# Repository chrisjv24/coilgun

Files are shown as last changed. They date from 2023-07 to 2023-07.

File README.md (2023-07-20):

# coilgun
This repository will contain all design files and documentation concerning the Carter X Chris coilgun design.

## Repo Architecture
The repo will be split into the four subsystems of chassis, propulsion, controls, and safety, along with an additional directory for non-technical documents.

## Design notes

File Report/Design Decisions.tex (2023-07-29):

\chapter{Design Decisions}
The system was divided into the following four subsystems: Mechanical Housing, Electrical Circuitry, Coding, and Safety. Each of these systems has their own unique design considerations that are to be explored and addressed.

\section{Electrical System}

The electrical system is the backbone of the project, being the main method of propulsion. This portion can be further broken down into the following: Power, capacitor charging, firing, and coil shutoff.

\subsection{Power}

The power system will need to provide adequate voltage for both the capacitors and micro-controller. The initial micro-controller choice is the Arduino Nano, which requires a 7-12V input. Therefore, either a 3S Lithium-Polymer (Li-Po) or 3 lithium ion 18650 batteries will be sufficient. This battery chemistry was chosen for its large capacity and the ability to recharge the batteries. However, to properly power the capacitor banks, a boost converter must be used to step up the battery voltage to 200-450V. A two stage DC-DC converter will be purchased off of Ali-Express to step up the voltage.

\begin{figure}
	
\end{figure}

The basic boost converter topology shown above can be characterized by first starting with the standard current and voltage equations for inductors and capacitors. 

For inductors, we have 
\begin{equation}
	V_{In}=L\frac{di}{dt}
\end{equation}

where \(V_{In}\) is the input voltage, L is the inductance of the inductor in Henries, and \(\frac{di}{dt}\) is the change in current across the inductor. For a single switching cycle, we have that \(\frac{di}{dt}\) is equal to the change in current across the period of the cycle, T. 

\begin{equation}
	V_{In}=L\frac{\Delta i}{T}
\end{equation}

Switching period is also defined as the inverse of the switching frequency \(f_S\). For the voltage across the inductor during only the ON portion of the cycle, the period is also multiplied by the duty cycle \(D\). Rearranging gives

\begin{equation}
	\Delta i=\frac{V_{In} D}{f_S L}
\end{equation}

Similarly, the capacitor can be modelled according to

\begin{equation}
	i=C_v\frac{dV}{dt}
\end{equation}

where \(C\) is the capacitance.
\subsubsection{Capacitor Charging}

The system will use 450V 1000uF capacitors to store energy. In order to charge the capacitors, direct connection to the boost converters will be required. An indicator with a digital display of the boost converter output voltage will be fixed onto the housing, with the assumption that, due to the low capacitance values, the capacitor charge simultaneously match the output. The digital voltage meter will consist of a voltage divider to step down 500V to within a 0-5V range. A voltage divider circuit can be simply modelled through Ohm's Law -- \(V=IR\). From the circuit diagram below, the voltage drop across \(R_2\) can be derived as follows

\begin{equation}
	V_in=IR_Total
	V_in
\end{equation}

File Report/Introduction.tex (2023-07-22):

\addcontentsline{toc}{chapter}{Introduction}
\chapter{Introduction}

Launching small projectiles is not a simple task. Traditional methods of propelling objects involve converting stored potential, such as chemical energy within gunpowder or mechanical energy stored in springs, into kinetic energy. However, electrical energy has been underutilized and often seen as a power source for motors or pumps rather than direct energy conversion. 

\section{Background Theory}
When an electric current flows through a wire, a magnetic field is induced. The strength and direction of this magnetic field are governed by the equation 

\begin{equation}
	\vec{B}(r)=\frac{\mu_0}{4\pi}\oint_C \frac{I \,dl \times (\vec{r}-\vec{r'})}{|\vec{r}-\vec{r'}|^3},
\end{equation} 

\noindent also known as the Biot-Savart Law, where \(\vec{B}(r)\) is the magnetic field at point \(r\) in teslas, \(I\) is current in Amperes, \(\,dl\) is a vector along path \(C\), \(r'\) is the position of source current at point \(l\), and \(\mu_0\) is the permeability of free space with a value of \(4\pi \times 10^-7 \frac{Tm}{A}\). If the wire were wound into loops, as in the case of a solenoid, then by placing the origin at the centre of the loops and calculating the magnetic field at \(r=0\), the magnetic field would be given by

\begin{equation}
	\vec{B}(r)=\frac{\mu_0}{4\pi}\oint_C \frac{I \,dl \times -\vec{r'}}{|\vec{r'}|^3}.
\end{equation}

\noindent For circular loops in a cylindrical coordinate system, the \(\,dl\) element is in the \(\hat{\phi}\) direction, \(\vec{r'}\) is only in the \(\hat{s}\) direction, and the cross product \(\,dl \times -\vec{r'}\) evaluates to be in the \(\hat{z}\) direction. Since a vector in the direction of the circular wire is always orthogonal to the radial vector \(\hat{s}\), the cross product integral (assuming a constant \(I\)) simplifies to 

\begin{equation}
	\vec{B}(r)=\frac{\mu_0 I}{4\pi}\hat{z}\oint_C \frac{ \,dl \vec{r'}}{|\vec{r'}|^3}=\frac{\mu_0 I}{4\pi r^2}\hat{z}\oint_C {\,dl}
\end{equation}

\noindent Here, the line integral evaluates to the length of the wire in the solenoid, which can be calculated by taking the circumference of the loops, $2\pi r$, multiplied by the number of loops $N$. Thus, the magnetic field is given by 

\begin{equation}
	\vec{B}=\frac{\mu_0 IN}{2r'}\hat{z}
\end{equation}

\noindent For a given projectile, its motion is described through Newton's Second Law. Assuming friction forces are negligible, then the acceleration of a ferromagnetic object of mass $m$ is 

\begin{equation}
	\vec{a} = \frac{\vec{F_{net}}}{m}=\frac{\vec{B}}{m}=\frac{\mu_0 IN}{2r'm}\hat{z}
\end{equation}

\noindent From the constant current assumption, the load must come from

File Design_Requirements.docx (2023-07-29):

# Coil Gun Electrical Product Design Requirements (PRD)

# High Level Overview

The goal is to create a modular multi-stage coil gun that accelerates a projectile through discharging high voltage capacitors through coils. The product must be battery powered and be controlled through a central MCU. The product should have a display indicating battery voltage level, capacitor voltage level, and status indicators. The user should have control over the charging and discharging of capacitors, as well as inputs over safety/deadmans switch active and projectile firing.

## High Level Parts Requirements

Firing Mechanism: High voltage capacitors, coils, electrical switch

Control: Microcontroller, Deadman’s switch, firing trigger, LCD screen, Battery Charge Indicator, Capacitor charge indicator, Not-safe LED, Speed sensor, Number of stages sensor

Power: Battery, buck voltage regulator, capacitor charging boost converter, Power-ON LED

Safety: ESD and EMI protection, EMC. RFID verification before access.

# Low Level Parts Requirements

Battery: LiPo, should take a 3s (11.1V nominal) for a range between 9V-12.6V. Set voltage range to 7-15V for flexibility. Will require a connector to board. Ideally high capacity.

RFID Tag + Reader: should be on the same frequency and power requirements, passive tags. COTS RFID module.

Buck Voltage Regulator: step down to MCU voltages, should take input of 7-15V and output 3.3V.

Boost converter: Step up 11V to 125V and further multiples. Output current irrelevant, charging time can take as long as required. Should have current limiting resistor in place as well. Should have a separate switch to enable.

Capacitors: High voltage rating, aiming for 400V+. High capacitance, aiming for 100uF < C < 1000uF

Microcontroller: Familiarity, ease of use. Requires debugger to flash firmware – STLink with SWD vs USB 2.0? Requires at least 2 ADC channels and an SPI, Timers for each stage.

USB: USB2.0, USBC connector

Deadman’s Switch: any basic switch, no specific requirements. Should not latch.

Electrical Firing switch: Required to be 400V compatible, ideally IGBT or high voltage FET/BJT. Fast response time.

Firing trigger: Any basic button, no specific requirements. Should not latch.

LCD Screen: minimize number of connection wires, use communication protocol. SPI preferred.

Coils: Easily modifiable, set length beforehand to plan wire routing.

Analog Components – Resistors, capacitors, op-amps, inductors, etc.

Connectors – Based on application, ideally all identical.

# Low Level Parts Selection

Battery:

Battery Connector:

Buck Converter:

Boost Converter:

Capacitors:

Capacitor Connector:

Coil Connector:

Microcontroller:

Deadman’s Switch:

Fire Switch:

Fire Trigger:

LCD Screen:

USB:

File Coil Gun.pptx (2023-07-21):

## Coil Gun

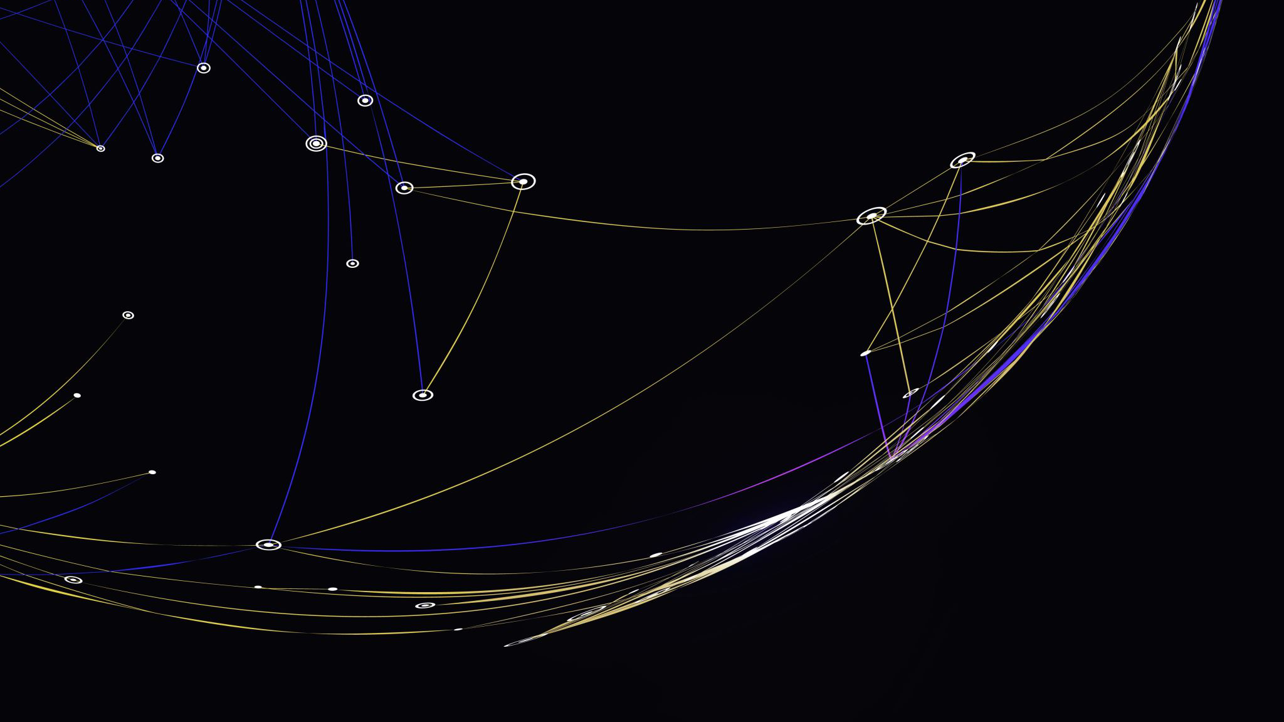
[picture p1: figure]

Zap

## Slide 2

Working Principles
Design Architecture
Safety Principles
Plan of Action

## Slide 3

Working Principles
Design Architecture
Safety Principles
Plan of Action

## Electromagnets

- Magnets that turn on and off via current running through wire
- Magnetic field generated via RHR
- Thumb in direction of current -> fingers coil in B-field
- Coil of wire has magnetic field produced strongest internally

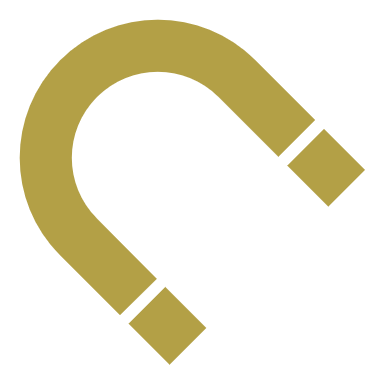
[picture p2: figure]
Magnet

## Magnetic Materials

- Ferromagnetic

- Attracted to both poles of a magnet, maintain magnetism after removal of external B-Fields

- Paramagnetic

- Attracted weakly to magnets, do not retain magnetism once B-field is removed

- Diamagnetic

- Repels magnets, does not retain magnetism once B-Field is removed

## Coil Attraction

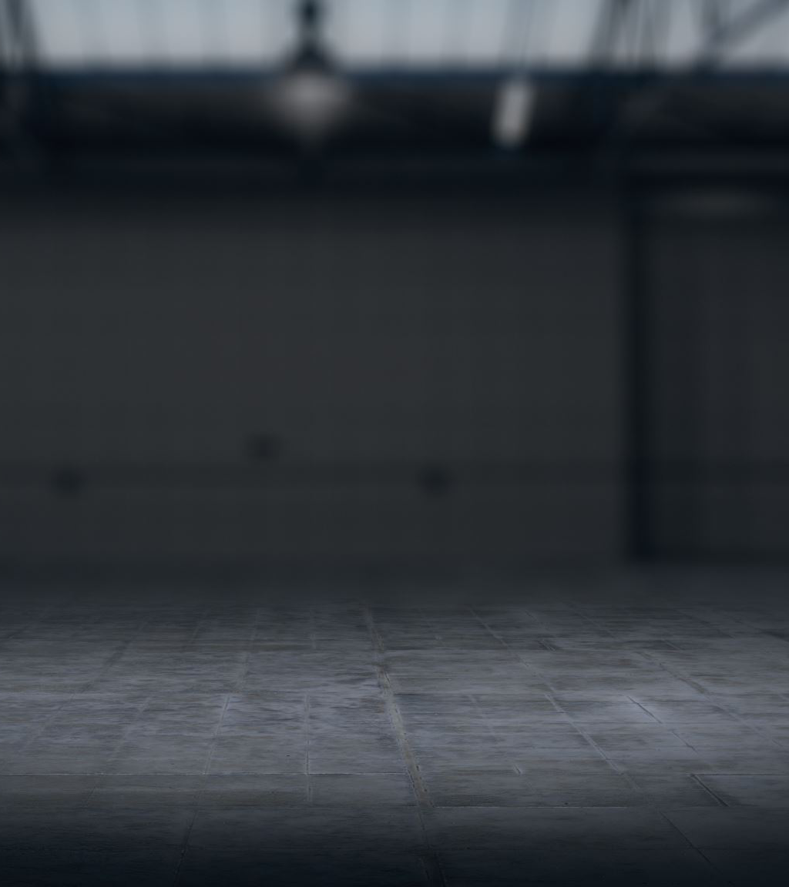
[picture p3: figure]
Interior of dark warehouse

- Ferromagnetic and Paramagnetic Materials attracted to the center of solenoids
- Diamagnetic materials repelled from centre of coils
- The stronger the B-Field produced, the stronger the force
- However, in isolation the materials get stuck in the middle of the coil for attractive forces, or can’t enter the coil in the first place for repulsive forces

## Coil Switching

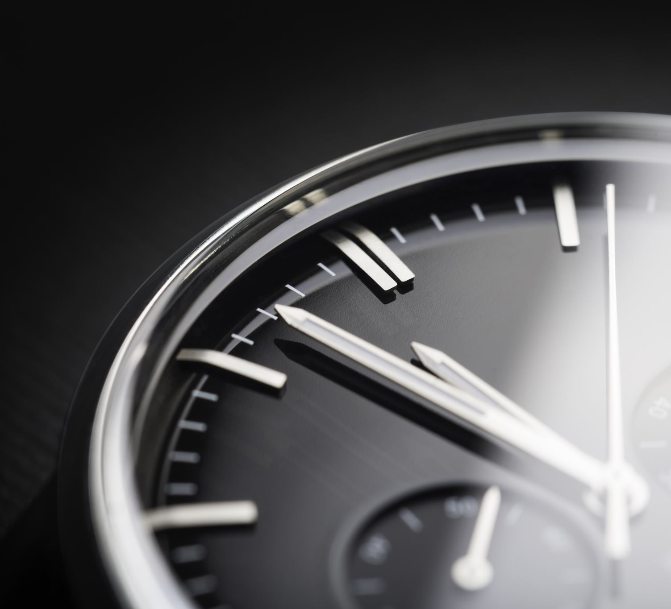
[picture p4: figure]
Wristwatch face

- This is why we use electromagnets instead of magnets
- For attractive forces -> cut current after the projectile is past halfway point
- For repulsive forces -> turn current on after projectile is past halfway point
- Can be done with sensors or timers

## How to generate a strong B-Field?

- B-Field Proportional to current and a few other properties
- Shorting a wire gives maximum current (internal wire resistance)
- For a given length of wire, a voltage has a maximum current
- Increase the voltage!
- Batteries and power supplies throttle current for protection
- Solution? Capacitors!

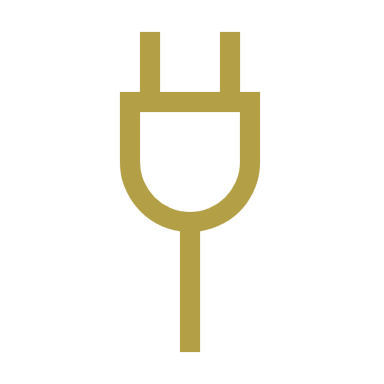
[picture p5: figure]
Plug

## Capacitors

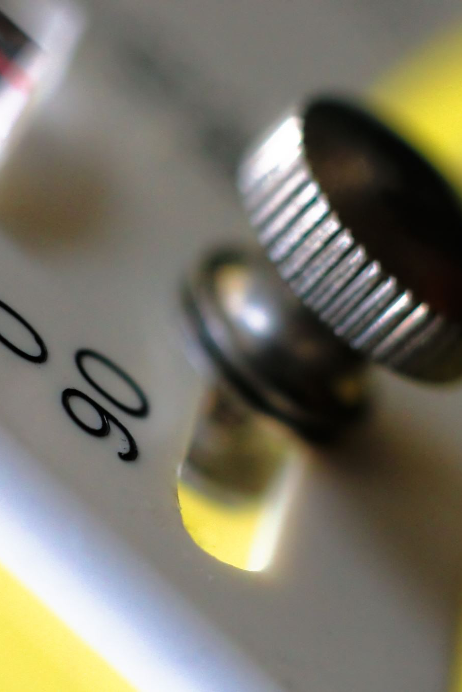
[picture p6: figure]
Adjustable measurement tool

- Charge caps to high voltage -> short caps through solenoid
- Isn’t shorting Capacitors dangerous?
- No! The coil is an inductor!

## Recap

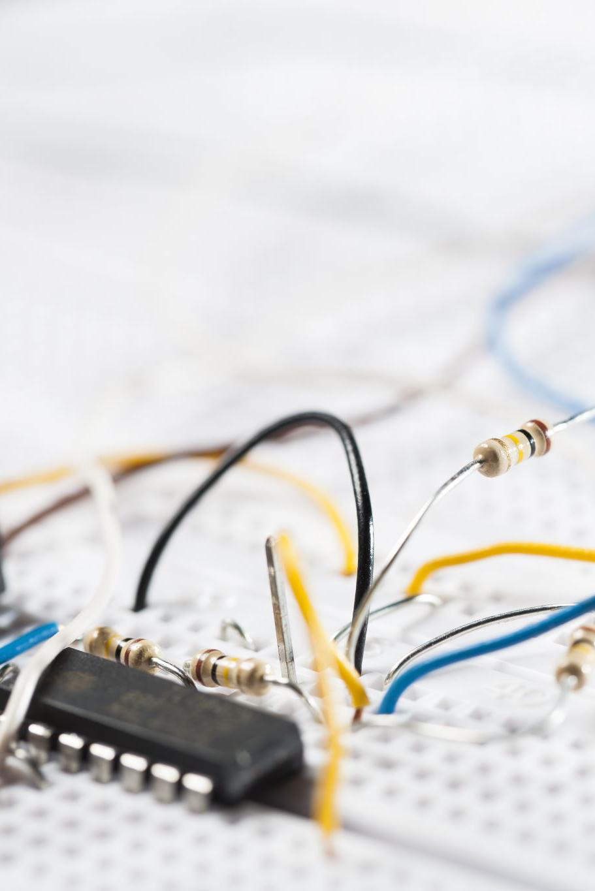
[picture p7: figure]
Electronics protoboard

- High voltage capacitors are charged
- Shorting the capacitors through coils produces strong B-fields
- B-Fields attract/repel magnetic materials to towards/away their center
- Sensors or timers are used to stop current flow and allow projectile to accelerate

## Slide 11

Working Principles
Design Architecture
Safety Principles
Plan of Action

## Coil Gun Subsystems

Chassis
Propulsion
Controls
Safety

## Chassis

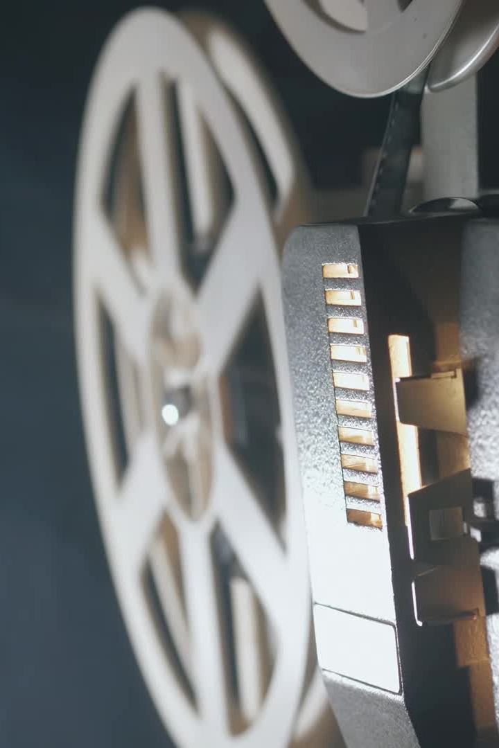
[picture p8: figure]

- Mechanical housing and mounting of all other subsystems
- Ergonomic handling, projectile barrel, component housing, trigger, reload point
- Coil and capacitor holder
- Overall aesthetic design

## Propulsion

- Coil parameters: number of windings, wire gauges, coil thickness, coil length
- Capacitor selection
- Capacitor charging circuit

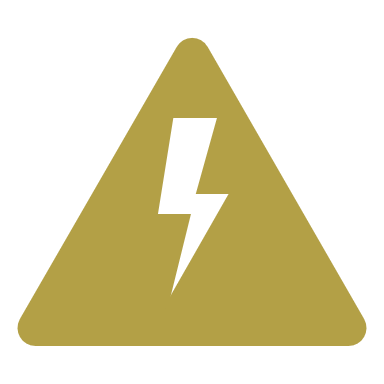
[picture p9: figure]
High Voltage

## Controls

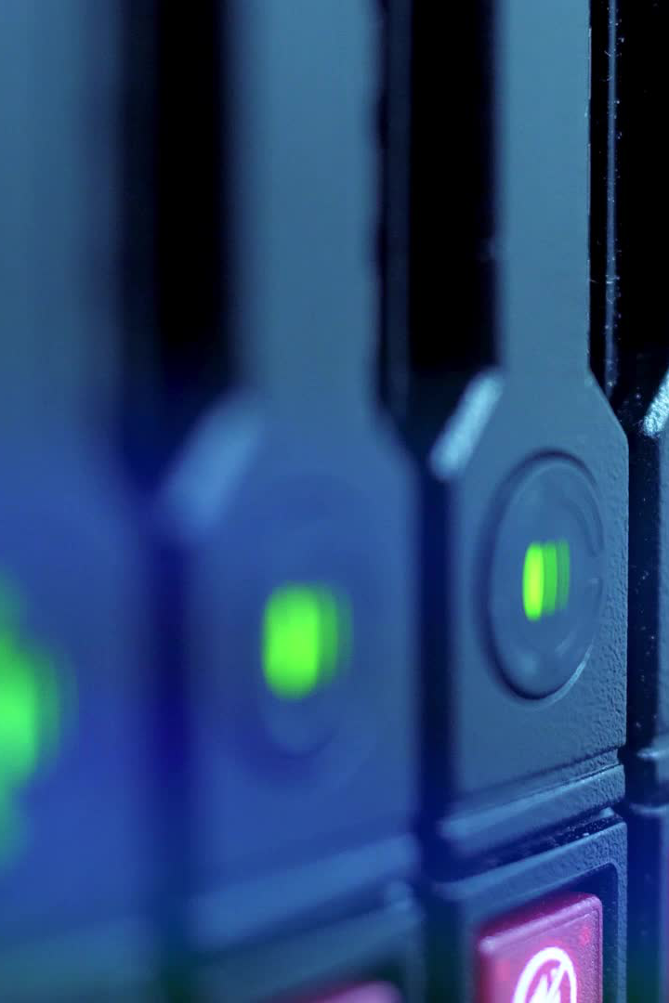
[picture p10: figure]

- External sensors or timers for current cut
- Voltage monitor
- UI -> LEDs, LCD Screens,
- Velocity monitor
- Adjustable power level

## Safety

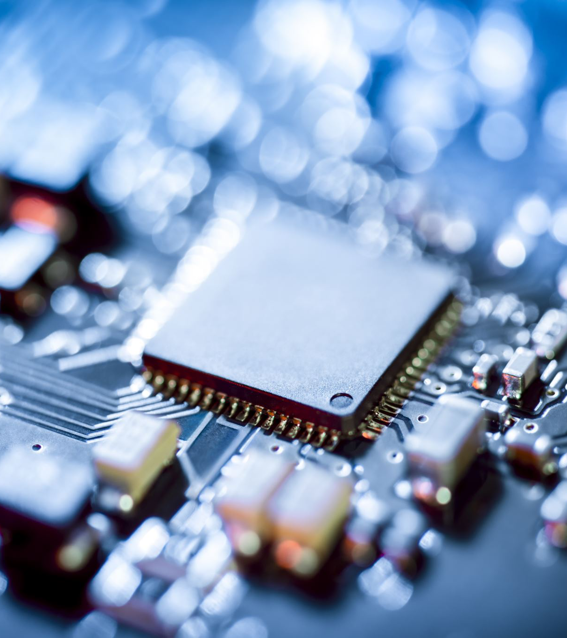
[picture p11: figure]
Circuit board

- Capacitor discharge circuit
- Mechanical capacitor discharge mechanism
- Bleeder Resistor
- Deadman’s switch
- Testing Rig, remote firing mechanism

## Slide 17

Working Principles
Design Architecture
Safety Principles
Plan of Action

## 1. High voltage capacitors

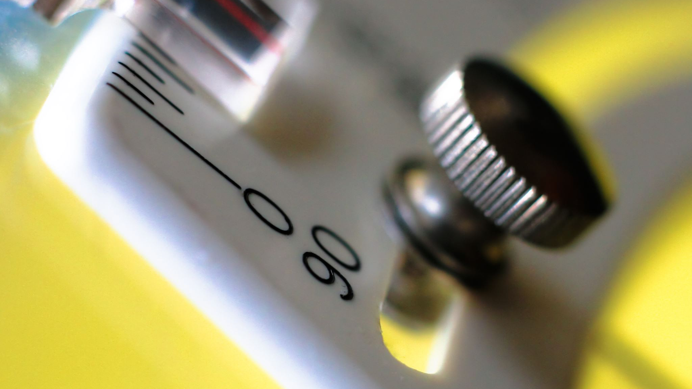
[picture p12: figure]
Adjustable measurement tool

- Capacitors discharge almost instantaneously when shorted
- Must stay under voltage rating
- Polarity!
- Reliable discharge methods, both mechanical and within system
- Passive discharge
- Video of capacitor short

## 2. Inductors

- Instant current cutoff causes inductor kickback
- Must include flyback diode

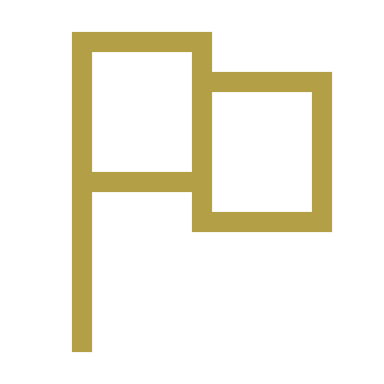
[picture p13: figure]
Flag

## 3. Component Ratings

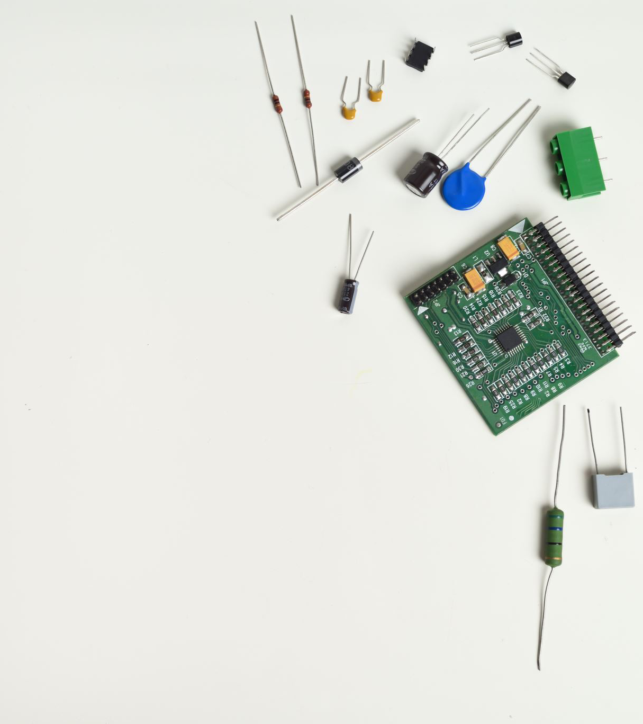
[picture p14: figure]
Electronic components on a white background

- All components in contact with HV wires need to be HV rated
- Mechanical switches in series can fuse together at high voltages
- Diode Breakdown voltages
- uC ratings
- HV can arc across small airgaps
- Resistor W ratings

## Safety Implementation

- Design

- Processes

- Bleeder resistors
- Capacitor discharge circuit
- Testing Rig
- Remote firing for testing
- Dead man’s switch
- Design to fail open

- Electrical gloves
- Safety Glasses
- Test outside
- Regular gun safety
- Checklist
- Indirect voltage measurement -terminals

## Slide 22

Working Principles
Design Architecture
Safety Principles
Plan of Action

## Design Division

- Chassis – CAD Design, Trigger mechanism, Deadman's switch, component mounting.
- Propulsion – Coil length, width, number of turns, and wire gauge. Capacitor selection.
- Controls – PCB design, Modularity, Speed sensing, UI (LCD screen, LEDS, variable power)
- Safety – Checklist, capacitor discharge circuit, mechanical discharge device, test rig,

## Proposed Plan

- Every meeting choose 1-3 things to complete for next meeting. If tasks are large/complex, further break down into individual tasks and choose
- Record everything we do
- Aim to have material ordered by Aug 2

## Bill of Materials

- Projectile + extras
- Barrel material
- PCB and electronic components
- HV capacitors
- COTS charging circuit?
- Sensors (speed, detection)

Housing Material (3D Print? Injection Molding? Vaccuum Molding? Custom Part order?)
Buttons, LEDS, LCDs
Wire for coils
Microcontroller
Sensors

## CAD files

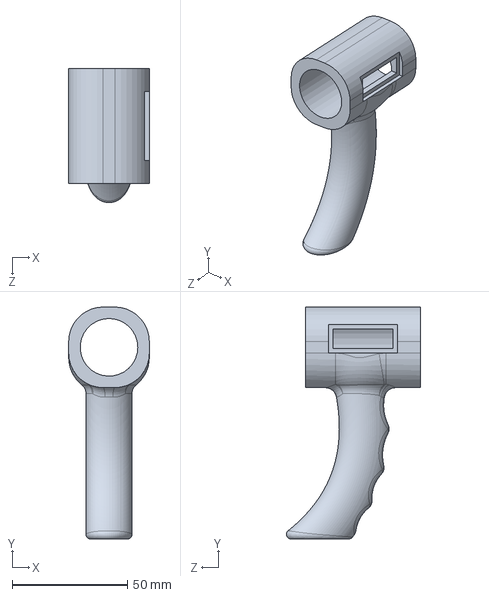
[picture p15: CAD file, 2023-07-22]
Chassis/Handle.SLDPRT
35.0 x 100.7 x 58.3 mm

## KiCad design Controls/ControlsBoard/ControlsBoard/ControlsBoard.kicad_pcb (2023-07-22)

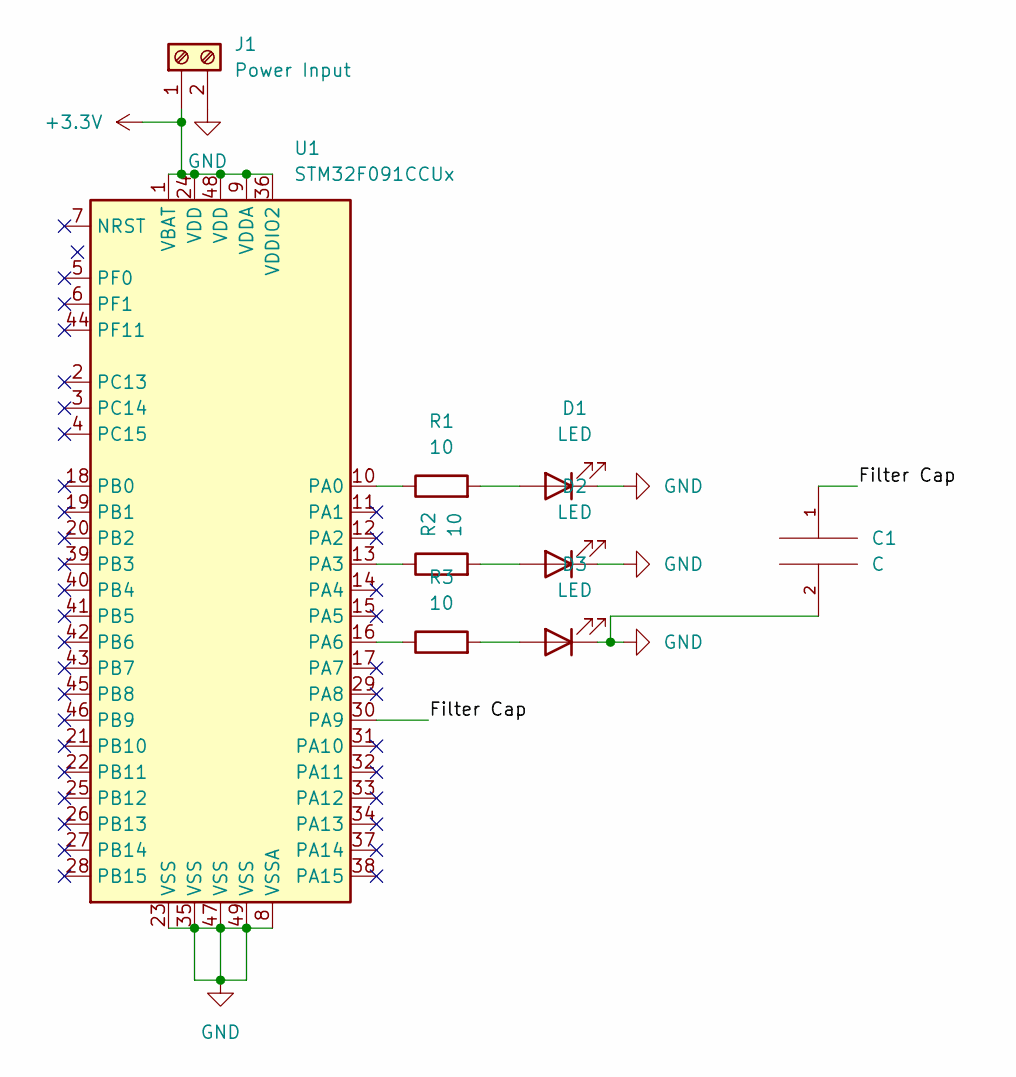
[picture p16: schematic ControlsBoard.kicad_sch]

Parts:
C1: C; C_0603_1608Metric
D1, D2, D3: LED; LED_0603_1608Metric
J1: Power Input; TerminalBlock_4Ucon_1x08_P3.50mm_Horizontal
R1, R2: 10; R_0805_2012Metric
R3: 10; R_Axial_DIN0207_L6.3mm_D2.5mm_P2.54mm_Vertical
U1: STM32F091CCUx; QFN-48-1EP_7x7mm_P0.5mm_EP5.6x5.6mm

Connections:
+3.3V: J1.1, U1.1 (VBAT), U1.9 (VDDA), U1.24 (VDD), U1.36 (VDDIO2), U1.48 (VDD)
/Filter Cap: C1.1, U1.30 (PA9)
GND: C1.2, D1.1 (K), D2.1 (K), D3.1 (K), J1.2, U1.8 (VSSA), U1.23 (VSS), U1.35 (VSS), U1.47 (VSS), U1.49 (VSS)
unnamed: D1.2 (A), R1.2
unnamed: D2.2 (A), R2.2
unnamed: D3.2 (A), R3.2
unnamed: R1.1, U1.10 (PA0)
unnamed: R2.1, U1.13 (PA3)
unnamed: R3.1, U1.16 (PA6)

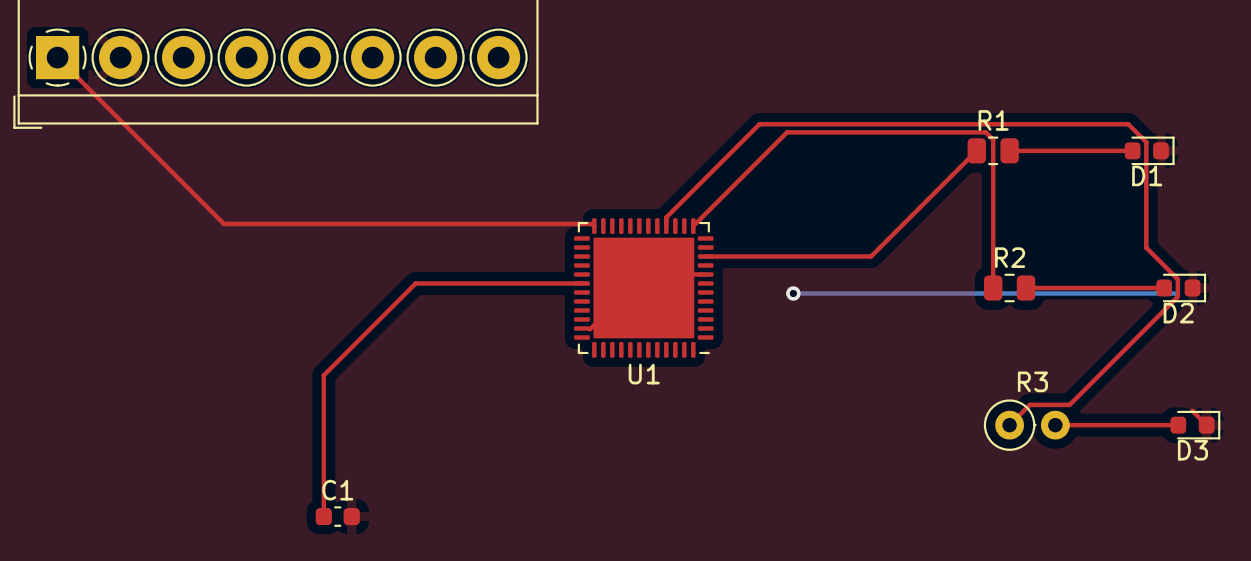
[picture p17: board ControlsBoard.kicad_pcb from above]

Board: 2 copper layers, 9 parts (0 on the bottom side), 9 nets.

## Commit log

2023-07-21 Adding powerpoint and gitignore
2023-07-22 Added Controls folder and PCB projects
    [ControlsBoard.kicad_pcb, ControlsBoard.kicad_sch]
2023-07-22 Added a budget folder and budget Excel sheet
    [Budget 1.xlsx]
2023-07-22 made a test PCB
    [ControlsBoard.kicad_pcb, ControlsBoard.kicad_sch]
2023-07-22 Preliminary design sketch of handle and reload
    [Handle.SLDPRT]
2023-07-23 Added Chassis Folder
    [Handle.SLDPRT]
